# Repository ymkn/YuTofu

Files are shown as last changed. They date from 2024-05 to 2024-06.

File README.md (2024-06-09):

# YuTofu

YuTofu is an unofficial compatible PCB for the well-known custom keyboard [Tofu60 2.0](https://kbdfans.com/products/tofu60-2-0).

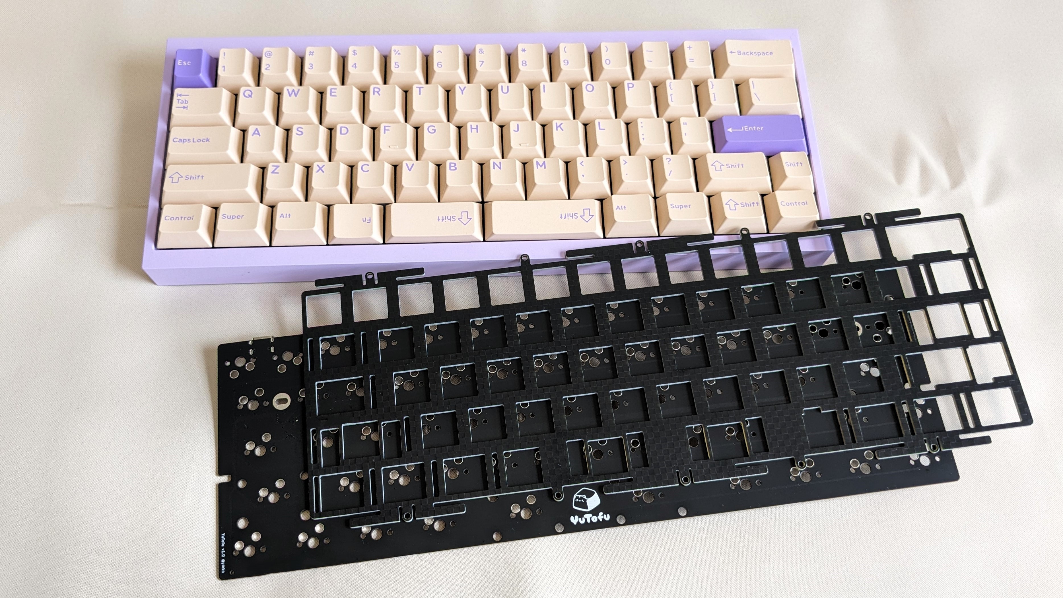
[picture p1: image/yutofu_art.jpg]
YuTofu Art


Based on an ANSI layout with splitted right-Shift and 6.25u spacebar, the spacebar area has been divided into 1.25u, 2.25u, and 2.75u sections. This allows for more effective use of the thumbs.

YuTofu is equipped with a 4-pin JSF socket compatible with [Unified Daughterboard](https://github.com/Unified-Daughterboard), in addition to an onboard USB Type-C connector and mounting holes compatible with the GH60-compatible layout. This means that the PCB can be used not only in the Tofu60 2.0 case but also in common GH60-compatible cases, i.e. [Tofu60 Redux Case](https://kbdfans.com/products/tofu60-redux-case).

## Default Layout

You can customize the layout with [Vial](https://get.vial.today/) configurator.

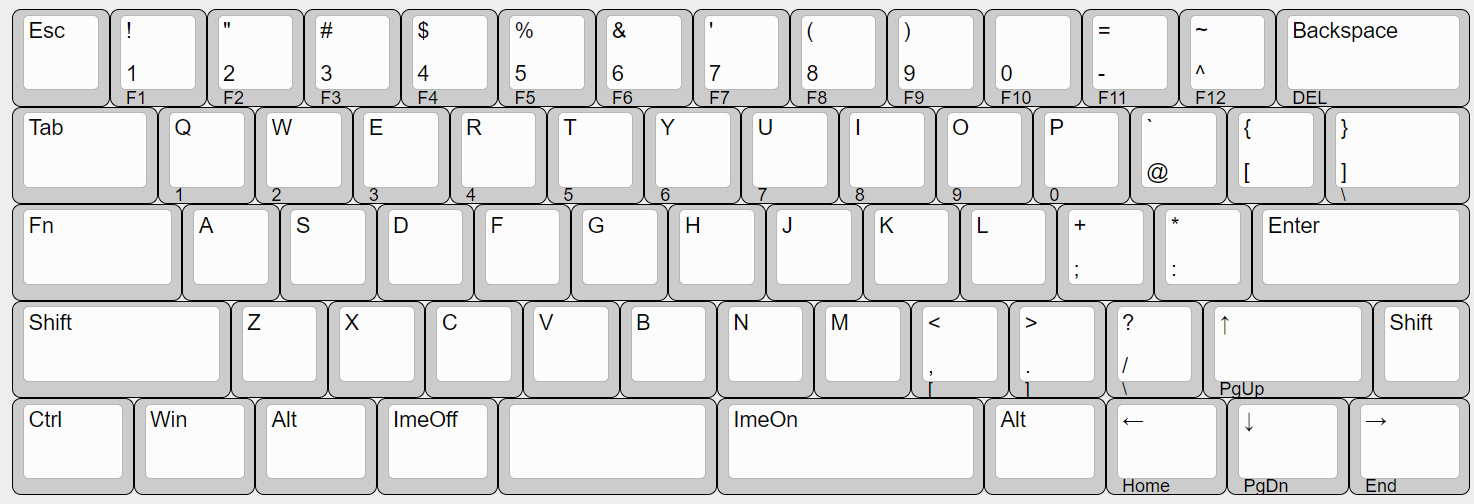
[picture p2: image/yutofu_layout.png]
Yutofu Layout


## Specification

- Hot swappable sockets for MX compatible switches are installed
- Unified-Daughterboard JSF 4-pin socket and USB Type C Connector (USB 2.0) are equipped
- PCB and switch plate compatible with the Tofu60 2.0
- GH60 compatible dimension: 285mm(w) x 94.6mm(h) x 1.6mm(d)
- Suitable for Tofu60 2.0 case, and also may be used for most 60% keyboard cases
  - Warning: center and right bottom mounting holes are not implemented.
  - Warning: switch plate cannot be used with cases other than the Tofu60 2.0.

## Build Guide

See [doc/buildguide.md](doc/buildguide.md)

## LICENSE

This project is licensed under the MIT License, see the [LICENSE file](LICENSE) for details.

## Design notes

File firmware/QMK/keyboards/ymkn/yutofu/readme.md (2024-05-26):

# ymkn/yutofu

YuTofu is an unofficial compatible PCB for the well-known custom keyboard [Tofu60 2.0](https://kbdfans.com/products/tofu60-2-0).

* Keyboard Maintainer: [ymkn](https://github.com/ymkn)

Make example for this keyboard (after setting up your build environment):

    make ymkn/yutofu:vial

Flashing example for this keyboard:

1. Enter the bootloader.
2. Simply copy ymkn_yutofu_vial.uf2 to RPI_RP2 drive.

This keyboard supports [Vial](https://get.vial.today/) configurator.

## Bootloader

Enter the bootloader in 2 ways:

* **Bootmagic reset**: Hold down the key at (0,0) in the matrix (usually the top left key or Escape) and plug in the keyboard
* **Physical reset button**: Briefly press the button on the back of the PCB - some may have pads you must short instead

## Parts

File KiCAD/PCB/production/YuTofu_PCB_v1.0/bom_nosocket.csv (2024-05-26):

Designator | Footprint | Quantity | Value | LCSC Part #
BTN1 | SW_Push_1P1T_XKB_TS-1187A | 1 | TS-1187A-B-A-B
C1, C2 | 0402 | 2 | 10uF
C10, C13, C16, C17, C3, C4, C5, C6, C7, C8, C9 | 0402 | 11 | 100nF
C11, C12 | 0402 | 2 | 1uF
C14, C15 | 0402 | 2 | 20pF
D1, D10, D11, D12, D13, D14, D15, D16, D17, D18, D19, D2, D20, D21, D22, D23, D24, D25, D26, D27, D28, D29, D3, D30, D31, D32, D33, D34, D35, D36, D37, D38, D39, D4, D40, D41, D42, D43, D44, D45, D46, D48, D49, D5, D50, D51, D52, D53, D54, D55, D56, D57, D58, D59, D6, D62, D63, D64, D65, D66, D67, D7, D8, D9 | D_SOD-123 | 64 | 1N4148W
J1 | USB_C_Receptacle_HRO_TYPE-C-31-M-12 | 1 | TYPE-C-31-M-12
J2 | JST_SH_SM04B-SRSS-TB_1x04-1MP_P1.00mm_Horizontal | 1 | Conn_01x04_MountingPin
R1, R3 | 0402 | 2 | 5.1K
R4, R5 | 0603 | 2 | 27
R6 | 0402 | 1 | 1KΩ
R7 | 0402 | 1 | 10kΩ
R8 | 0402 | 1 | 1K
U1 | SOT-23-3 | 1 | XC6206P332MR
U2 | SOT-363-6_2P2X1P35_ONS | 1 | SMF05CT1G
U3 | QFN-56-1EP_7x7mm_P0.4mm_EP3.2x3.2mm | 1 | RP2040
U4 | W25Q16JVUXIQ_WIN | 1 | W25Q16JVUXIQ
Y1 | Crystal_SMD_3225-4Pin_3.2x2.5mm | 1 | X322512MSB4SI

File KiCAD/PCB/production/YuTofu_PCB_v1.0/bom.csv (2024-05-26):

Designator | Footprint | Quantity | Value | LCSC Part #
BTN1 | SW_Push_1P1T_XKB_TS-1187A | 1 | TS-1187A-B-A-B
C1, C2 | 0402 | 2 | 10uF
C10, C13, C16, C17, C3, C4, C5, C6, C7, C8, C9 | 0402 | 11 | 100nF
C11, C12 | 0402 | 2 | 1uF
C14, C15 | 0402 | 2 | 20pF
D1, D10, D11, D12, D13, D14, D15, D16, D17, D18, D19, D2, D20, D21, D22, D23, D24, D25, D26, D27, D28, D29, D3, D30, D31, D32, D33, D34, D35, D36, D37, D38, D39, D4, D40, D41, D42, D43, D44, D45, D46, D48, D49, D5, D50, D51, D52, D53, D54, D55, D56, D57, D58, D59, D6, D62, D63, D64, D65, D66, D67, D7, D8, D9 | D_SOD-123 | 64 | 1N4148W
J1 | USB_C_Receptacle_HRO_TYPE-C-31-M-12 | 1 | TYPE-C-31-M-12
J2 | JST_SH_SM04B-SRSS-TB_1x04-1MP_P1.00mm_Horizontal | 1 | Conn_01x04_MountingPin
R1, R3 | 0402 | 2 | 5.1K
R4, R5 | 0603 | 2 | 27
R6 | 0402 | 1 | 1KΩ
R7 | 0402 | 1 | 10kΩ
R8 | 0402 | 1 | 1K
SW1, SW11, SW12, SW13, SW14, SW16, SW17, SW18, SW19, SW21, SW22, SW23, SW24, SW25, SW26, SW27, SW28, SW30, SW31, SW32, SW33, SW34, SW35, SW36, SW37, SW38, SW39, SW4, SW40, SW41, SW42, SW43, SW44, SW45, SW46, SW48, SW49, SW50, SW51, SW53, SW54, SW55, SW58, SW59, SW6, SW66, SW7, SW8, SW9 | SW_MX_HS_CPG151101S11_1u | 49 | SW_Push
SW10, SW15, SW20, SW5, SW52, SW57, SW62, SW67 | SW_MX_HS_CPG151101S11_1.25u | 8 | SW_Push
SW2 | SW_MX_HS_CPG151101S11_1.5u | 1 | SW_Push
SW29 | SW_MX_HS_CPG151101S11_1u | 1 | Space
SW3, SW56 | SW_MX_HS_CPG151101S11_1.75u | 2 | SW_Push
SW63 | SW_MX_HS_CPG151101S11_1u | 1 | Backspace
SW64 | SW_MX_HS_CPG151101S11_1.5u | 1 | Backslash
SW65 | SW_MX_HS_CPG151101S11_1u | 1 | Enter
U1 | SOT-23-3 | 1 | XC6206P332MR
U2 | SOT-363-6_2P2X1P35_ONS | 1 | SMF05CT1G
U3 | QFN-56-1EP_7x7mm_P0.4mm_EP3.2x3.2mm | 1 | RP2040
U4 | W25Q16JVUXIQ_WIN | 1 | W25Q16JVUXIQ
Y1 | Crystal_SMD_3225-4Pin_3.2x2.5mm | 1 | X322512MSB4SI

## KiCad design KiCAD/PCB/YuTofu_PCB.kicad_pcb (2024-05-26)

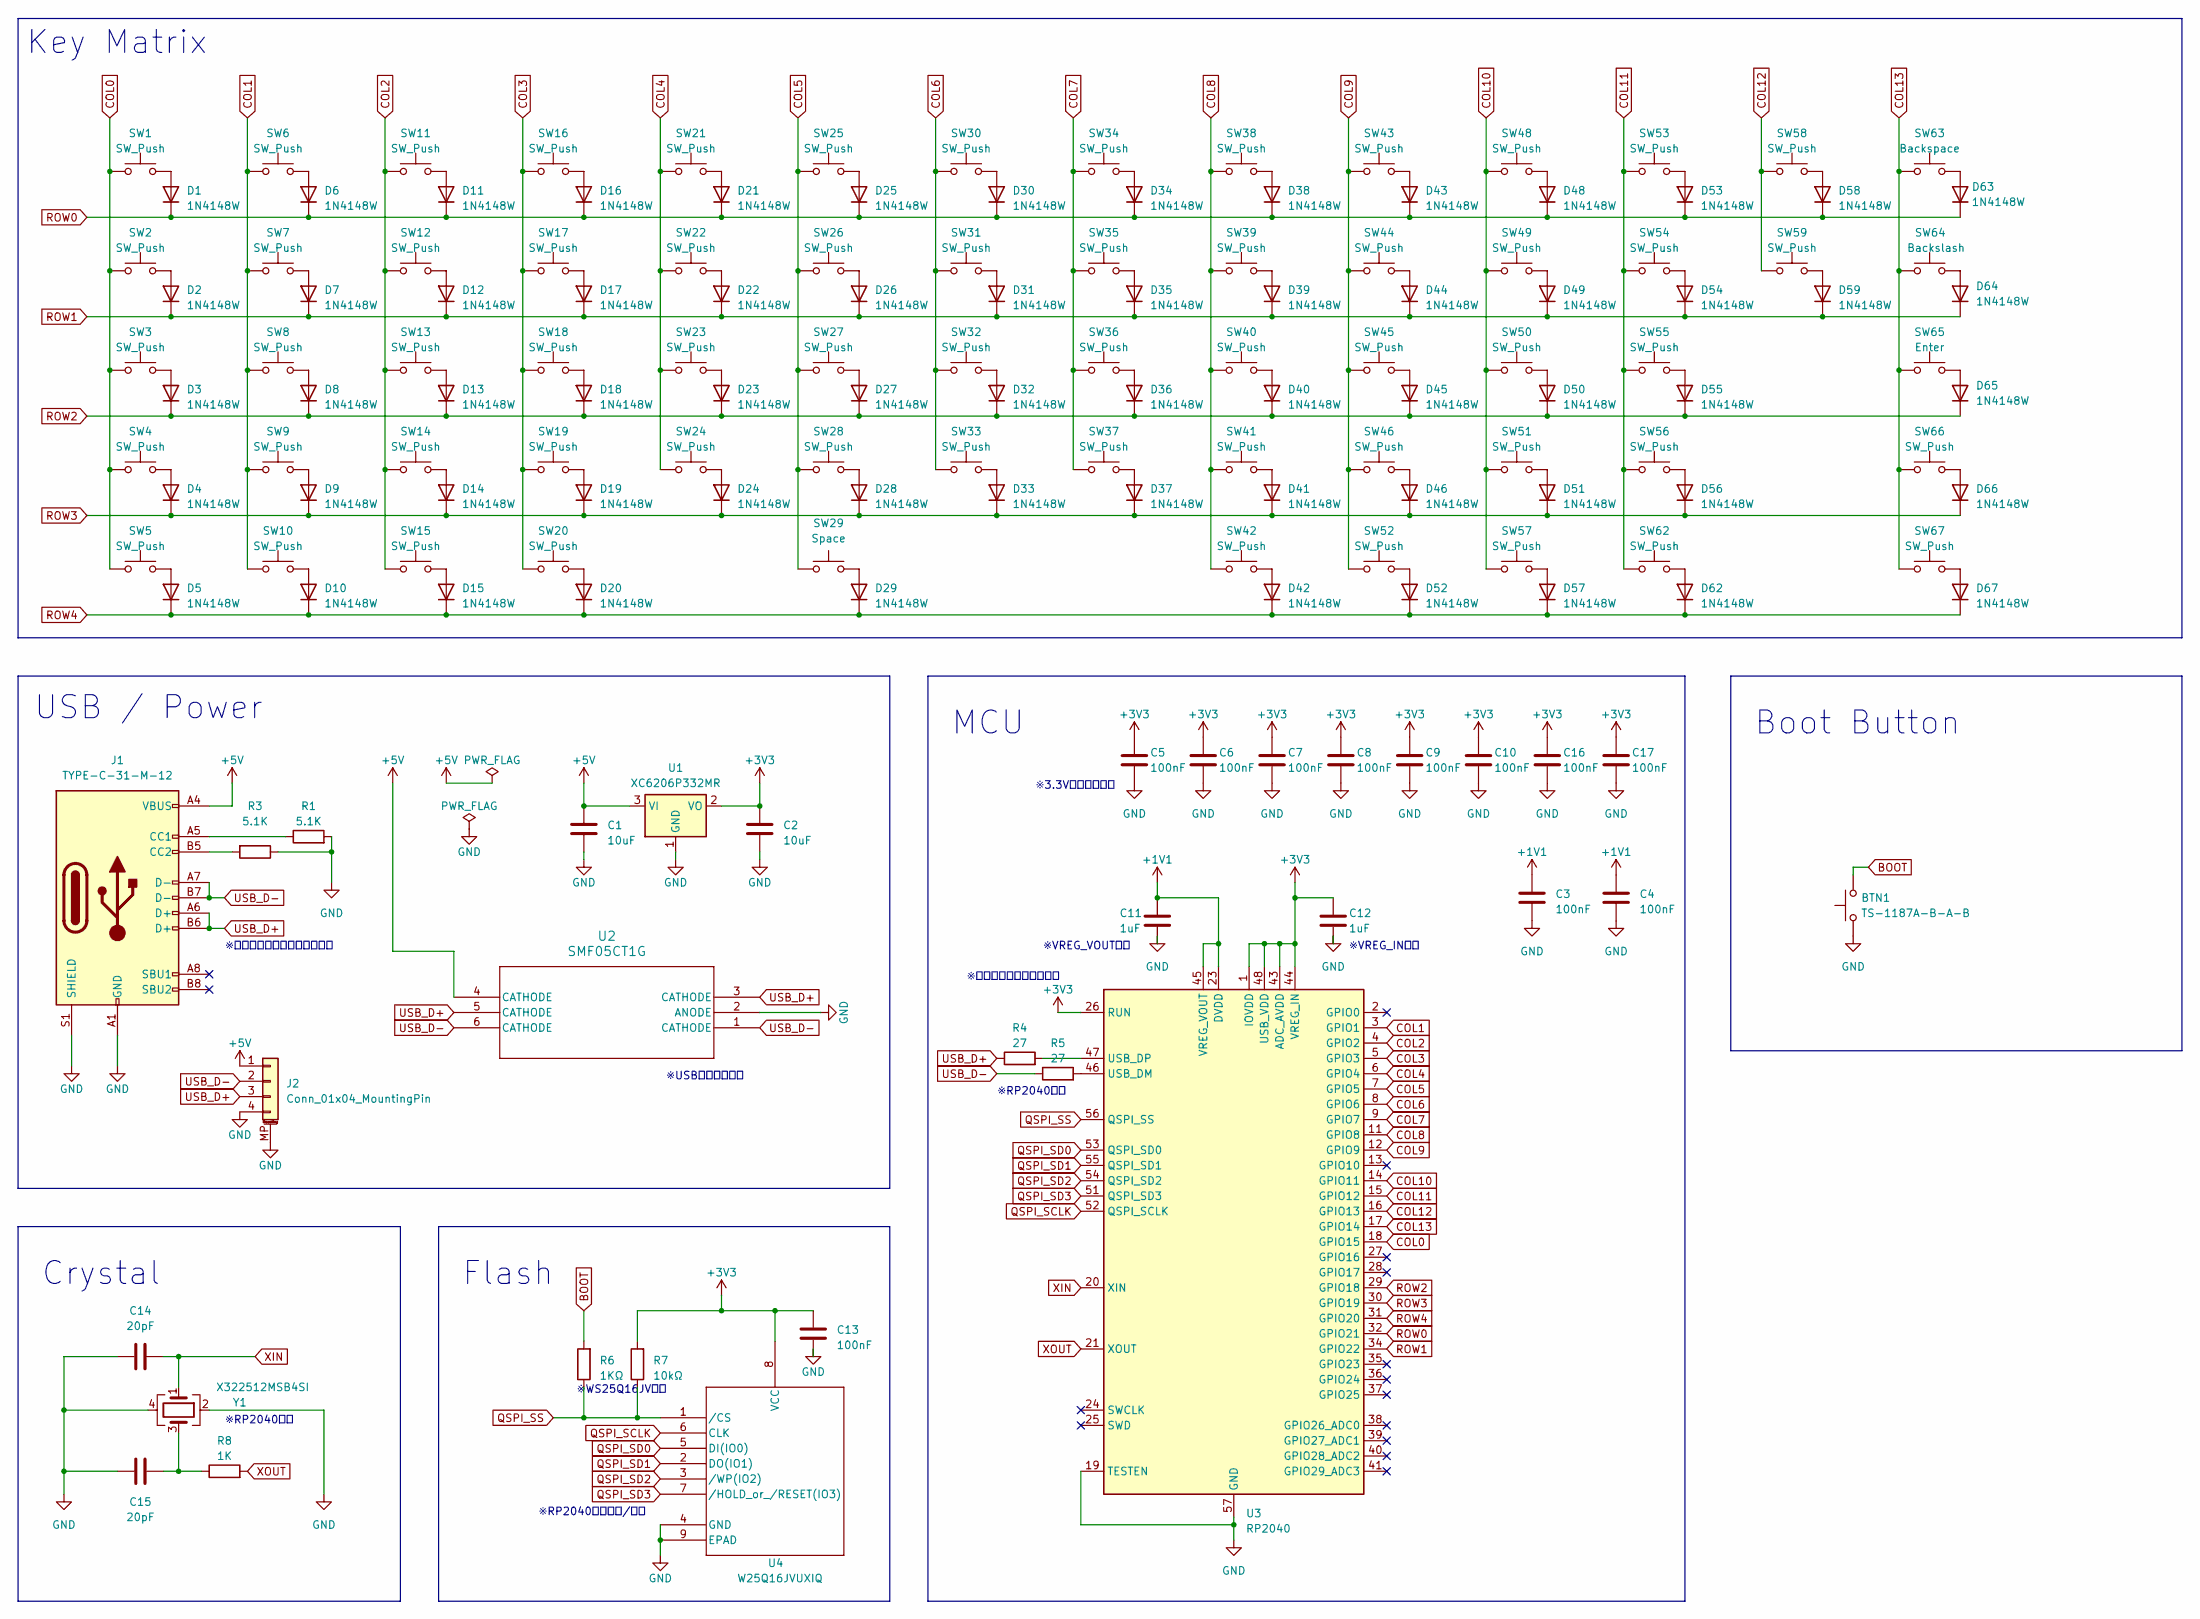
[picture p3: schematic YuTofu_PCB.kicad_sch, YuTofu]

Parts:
BTN1: TS-1187A-B-A-B; SW_Push_1P1T_XKB_TS-1187A; LCSC Parts # C318884
C1, C2: 10uF; C_0402_1005Metric; LCSC Parts # C15525
C3, C4, C5, C6, C7, C8, C9, C10, C13, C16, C17: 100nF; C_0402_1005Metric; LCSC Parts # C1525
C11, C12: 1uF; C_0402_1005Metric; LCSC Parts # C52923
C14, C15: 20pF; C_0402_1005Metric; LCSC Parts # C1554
D1, D2, D3, D4, D5, D6, D7, D8, D9, D10, D11, D12, D13, D14, D15, D16, D17, D18, D19, D20, D21, D22, D23, D24, D25, D26, D27, D28, D29, D30, D31, D32, D33, D34, D35, D36, D37, D38, D39, D40, D41, D42, D43, D44, D45, D46, D48, D49, D50, D51, D52, D53, D54, D55, D56, D57, D58, D59, D62, D63, D64, D65, D66, D67: 1N4148W; D_SOD-123; LCSC Parts # C7420318
J1: TYPE-C-31-M-12; USB_C_Receptacle_HRO_TYPE-C-31-M-12; LCSC Parts # C165948
J2: Conn_01x04_MountingPin; JST_SH_SM04B-SRSS-TB_1x04-1MP_P1.00mm_Horizontal; LCSC Parts # C160404
R1, R3: 5.1K; R_0402_1005Metric; LCSC Parts # C25905
R4, R5: 27; R_0603_1608Metric; LCSC Parts # C13167
R6: 1KΩ; R_0402_1005Metric; LCSC Parts # C11702
R7: 10kΩ; R_0402_1005Metric; LCSC Parts # C25744
R8: 1K; R_0402_1005Metric; LCSC Parts # C11702
SW1, SW4, SW6, SW7, SW8, SW9, SW11, SW12, SW13, SW14, SW16, SW17, SW18, SW19, SW21, SW22, SW23, SW24, SW25, SW26, SW27, SW28, SW30, SW31, SW32, SW33, SW34, SW35, SW36, SW37, SW38, SW39, SW40, SW41, SW42, SW43, SW44, SW45, SW46, SW48, SW49, SW50, SW51, SW53, SW54, SW55, SW58, SW59, SW66: SW_Push; SW_MX_HS_CPG151101S11_1u
SW2: SW_Push; SW_MX_HS_CPG151101S11_1.5u
SW3, SW56: SW_Push; SW_MX_HS_CPG151101S11_1.75u
SW5, SW10, SW15, SW20, SW52, SW57, SW62, SW67: SW_Push; SW_MX_HS_CPG151101S11_1.25u
SW29: Space; SW_MX_HS_CPG151101S11_1u
SW63: Backspace; SW_MX_HS_CPG151101S11_1u
SW64: Backslash; SW_MX_HS_CPG151101S11_1.5u
SW65: Enter; SW_MX_HS_CPG151101S11_1u
U1: XC6206P332MR; SOT-23-3; LCSC Parts # C5446
U2: SMF05CT1G; SOT-363-6_2P2X1P35_ONS; LCSC Parts # C15879
U3: RP2040; QFN-56-1EP_7x7mm_P0.4mm_EP3.2x3.2mm; LCSC Parts # C2040
U4: W25Q16JVUXIQ; W25Q16JVUXIQ_WIN; LCSC Parts # C2843335
Y1: X322512MSB4SI; Crystal_SMD_3225-4Pin_3.2x2.5mm; LCSC Parts # C9002

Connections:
+1V1: C3.1, C4.1, C11.1, U3.23 (DVDD), U3.45 (VREG_VOUT), U3.50 (DVDD)
+3V3: C2.1, C5.1, C6.1, C7.1, C8.1, C9.1, C10.1, C12.1, C13.1, C16.1, C17.1, R7.2, U1.2 (VO), U3.1 (IOVDD), U3.10 (IOVDD), U3.22 (IOVDD), U3.26 (RUN), U3.33 (IOVDD), U3.42 (IOVDD), U3.43 (ADC_AVDD), U3.44 (VREG_IN), U3.48 (USB_VDD), U3.49 (IOVDD), U4.8 (VCC)
+5V: C1.1, J1.A4 (VBUS), J1.A9 (VBUS), J1.B4 (VBUS), J1.B9 (VBUS), J2.1, U1.3 (VI), U2.4 (CATHODE)
BOOT: BTN1.2, R6.2
COL0: SW1.1, SW2.1, SW3.1, SW4.1, SW5.1, U3.18 (GPIO15)
COL1: SW6.1, SW7.1, SW8.1, SW9.1, SW10.1, U3.3 (GPIO1)
COL2: SW11.1, SW12.1, SW13.1, SW14.1, SW15.1, U3.4 (GPIO2)
COL3: SW16.1, SW17.1, SW18.1, SW19.1, SW20.1, U3.5 (GPIO3)
COL4: SW21.1, SW22.1, SW23.1, SW24.1, U3.6 (GPIO4)
COL5: SW25.1, SW26.1, SW27.1, SW28.1, SW29.1, U3.7 (GPIO5)
COL6: SW30.1, SW31.1, SW32.1, SW33.1, U3.8 (GPIO6)
COL7: SW34.1, SW35.1, SW36.1, SW37.1, U3.9 (GPIO7)
COL8: SW38.1, SW39.1, SW40.1, SW41.1, SW42.1, U3.11 (GPIO8)
COL9: SW43.1, SW44.1, SW45.1, SW46.1, SW52.1, U3.12 (GPIO9)
COL10: SW48.1, SW49.1, SW50.1, SW51.1, SW57.1, U3.14 (GPIO11)
COL11: SW53.1, SW54.1, SW55.1, SW56.1, SW62.1, U3.15 (GPIO12)
COL12: SW58.1, SW59.1, U3.16 (GPIO13)
COL13: SW63.1, SW64.1, SW65.1, SW66.1, SW67.1, U3.17 (GPIO14)
GND: BTN1.1, C1.2, C2.2, C3.2, C4.2, C5.2, C6.2, C7.2, C8.2, C9.2, C10.2, C11.2, C12.2, C13.2, C14.1, C15.1, C16.2, C17.2, J1.A1 (GND), J1.A12 (GND), J1.B1 (GND), J1.B12 (GND), J1.S1 (SHIELD), J2.4, J2.MP (MountPin), R1.2, R3.1, U1.1 (GND), U2.2 (ANODE), U3.19 (TESTEN), U3.57 (GND), U4.4 (GND), U4.9 (EPAD), Y1.2, Y1.4
unnamed: C15.2, R8.1, Y1.3
unnamed: D1.2 (A), SW1.2
unnamed: D2.2 (A), SW2.2
unnamed: D3.2 (A), SW3.2
unnamed: D4.2 (A), SW4.2
unnamed: D5.2 (A), SW5.2
unnamed: D6.2 (A), SW6.2
unnamed: D7.2 (A), SW7.2
unnamed: D8.2 (A), SW8.2
unnamed: D9.2 (A), SW9.2
unnamed: D10.2 (A), SW10.2
unnamed: D11.2 (A), SW11.2
unnamed: D12.2 (A), SW12.2
unnamed: D13.2 (A), SW13.2
unnamed: D14.2 (A), SW14.2
unnamed: D15.2 (A), SW15.2
unnamed: D16.2 (A), SW16.2
unnamed: D17.2 (A), SW17.2
unnamed: D18.2 (A), SW18.2
unnamed: D19.2 (A), SW19.2
unnamed: D20.2 (A), SW20.2
unnamed: D21.2 (A), SW21.2
unnamed: D22.2 (A), SW22.2
unnamed: D23.2 (A), SW23.2
unnamed: D24.2 (A), SW24.2
unnamed: D25.2 (A), SW25.2
unnamed: D26.2 (A), SW26.2
unnamed: D27.2 (A), SW27.2
unnamed: D28.2 (A), SW28.2
unnamed: D29.2 (A), SW29.2
unnamed: D30.2 (A), SW30.2
unnamed: D31.2 (A), SW31.2
unnamed: D32.2 (A), SW32.2
unnamed: D33.2 (A), SW33.2
unnamed: D34.2 (A), SW34.2
unnamed: D35.2 (A), SW35.2
unnamed: D36.2 (A), SW36.2
unnamed: D37.2 (A), SW37.2
unnamed: D38.2 (A), SW38.2
unnamed: D39.2 (A), SW39.2
unnamed: D40.2 (A), SW40.2
unnamed: D41.2 (A), SW41.2
unnamed: D42.2 (A), SW42.2
unnamed: D43.2 (A), SW43.2
unnamed: D44.2 (A), SW44.2
unnamed: D45.2 (A), SW45.2
unnamed: D46.2 (A), SW46.2
unnamed: D48.2 (A), SW48.2
unnamed: D49.2 (A), SW49.2
unnamed: D50.2 (A), SW50.2
unnamed: D51.2 (A), SW51.2
unnamed: D52.2 (A), SW52.2
unnamed: D53.2 (A), SW53.2
unnamed: D54.2 (A), SW54.2
unnamed: D55.2 (A), SW55.2
unnamed: D56.2 (A), SW56.2
unnamed: D57.2 (A), SW57.2
unnamed: D58.2 (A), SW58.2
unnamed: D59.2 (A), SW59.2
unnamed: D62.2 (A), SW62.2
unnamed: D63.2 (A), SW63.2
unnamed: D64.2 (A), SW64.2
unnamed: D65.2 (A), SW65.2
unnamed: D66.2 (A), SW66.2
unnamed: D67.2 (A), SW67.2
unnamed: J1.A5 (CC1), R1.1
unnamed: J1.B5 (CC2), R3.2
unnamed: R5.2, U3.46 (USB_DM)
unnamed: R4.2, U3.47 (USB_DP)
QSPI_SCLK: U3.52 (QSPI_SCLK), U4.6 (CLK)
QSPI_SD0: U3.53 (QSPI_SD0), U4.5 (DI(IO0))
QSPI_SD1: U3.55 (QSPI_SD1), U4.2 (DO(IO1))
QSPI_SD2: U3.54 (QSPI_SD2), U4.3 (/WP(IO2))
QSPI_SD3: U3.51 (QSPI_SD3), U4.7 (/HOLD_or_/RESET(IO3))
QSPI_SS: R6.1, R7.1, U3.56 (QSPI_SS), U4.1 (/CS)
ROW0: D1.1 (K), D6.1 (K), D11.1 (K), D16.1 (K), D21.1 (K), D25.1 (K), D30.1 (K), D34.1 (K), D38.1 (K), D43.1 (K), D48.1 (K), D53.1 (K), D58.1 (K), D63.1 (K), U3.32 (GPIO21)
ROW1: D2.1 (K), D7.1 (K), D12.1 (K), D17.1 (K), D22.1 (K), D26.1 (K), D31.1 (K), D35.1 (K), D39.1 (K), D44.1 (K), D49.1 (K), D54.1 (K), D59.1 (K), D64.1 (K), U3.34 (GPIO22)
ROW2: D3.1 (K), D8.1 (K), D13.1 (K), D18.1 (K), D23.1 (K), D27.1 (K), D32.1 (K), D36.1 (K), D40.1 (K), D45.1 (K), D50.1 (K), D55.1 (K), D65.1 (K), U3.29 (GPIO18)
ROW3: D4.1 (K), D9.1 (K), D14.1 (K), D19.1 (K), D24.1 (K), D28.1 (K), D33.1 (K), D37.1 (K), D41.1 (K), D46.1 (K), D51.1 (K), D56.1 (K), D66.1 (K), U3.30 (GPIO19)
ROW4: D5.1 (K), D10.1 (K), D15.1 (K), D20.1 (K), D29.1 (K), D42.1 (K), D52.1 (K), D57.1 (K), D62.1 (K), D67.1 (K), U3.31 (GPIO20)
USB_D+: J1.A6 (D+), J1.B6 (D+), J2.3, R4.1, U2.3 (CATHODE), U2.5 (CATHODE)
USB_D-: J1.A7 (D-), J1.B7 (D-), J2.2, R5.1, U2.1 (CATHODE), U2.6 (CATHODE)
XIN: C14.2, U3.20 (XIN), Y1.1
XOUT: R8.2, U3.21 (XOUT)

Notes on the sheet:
※RP2040近傍
Flash
Key Matrix
※リセットボタン実装無し
USB / Power
※WS25Q16JV近傍
※USBコネクタ近傍
※差動信号、配線長さ合わせる
※VREG_IN近傍
Boot Button
MCU
※3.3V電源ピン近傍
※RP2040近傍配置/直結
※VREG_VOUT近傍
Crystal

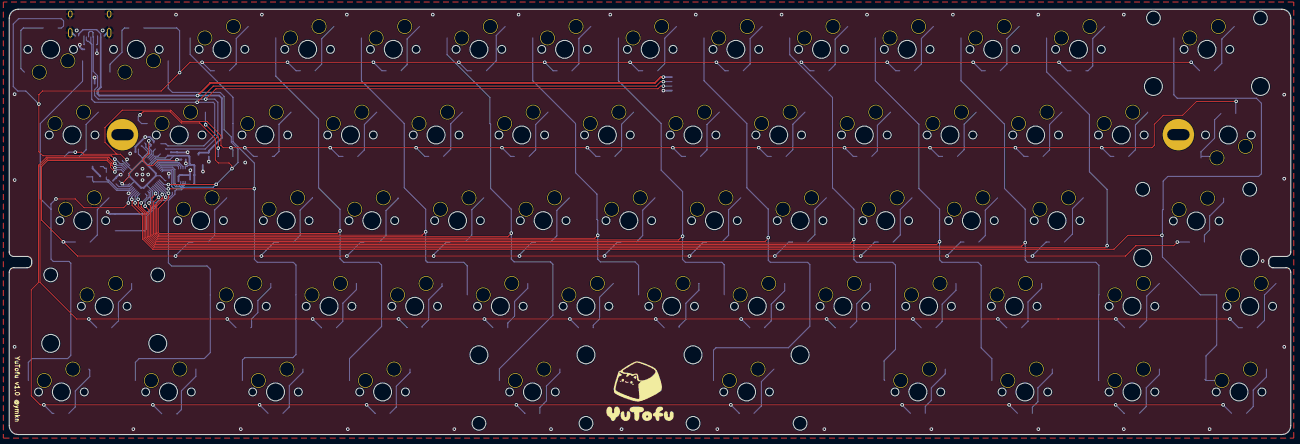
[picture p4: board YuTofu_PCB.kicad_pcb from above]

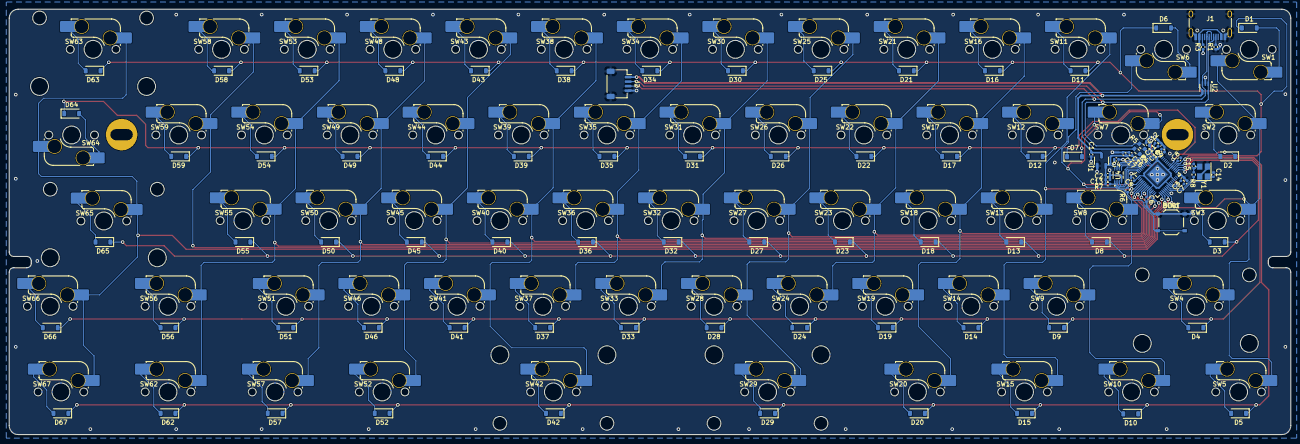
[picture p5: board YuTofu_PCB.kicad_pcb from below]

Board: 2 copper layers, 285.1 x 94.6 mm, 160 parts (160 on the bottom side), 103 nets.

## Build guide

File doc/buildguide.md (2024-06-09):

# YuTofu ビルドガイド

## 1. はじめに

本書は[Tofu60 2.0](https://kbdfans.com/products/tofu60-2-0)互換の自作キーボード基板であるYuTofuのビルドガイドです。Tofu60 2.0との組み合わせ利用以外は想定しておりませんのでご留意ください。

申し訳ないのですがYuTofu固有でない一般のご質問や、互換性確認済みケース以外についてのご質問にはお答えできません。各自お調べください。

> [!CAUTION]
> <em style="color: red; font-style: normal; font-weight: bold;">JSTコネクタとYuTofu基板上のUSBコネクタを同時にPCへ接続しないでください。YuTofuやPCの故障の危険性があります。</em>JSTコネクタ利用時はドーターボード側のUSBコネクタのみを使用し、YuTofu基板上のUSBコネクタを使用する場合はJSTコネクタに何も接続しないでください。

## 2. 準備

### 2.1 内容物確認

|品目|数量|
|---|---|
|YuTofu 基板|1|
|YuTofu スイッチプレート (Tofu60 2.0互換)|1|

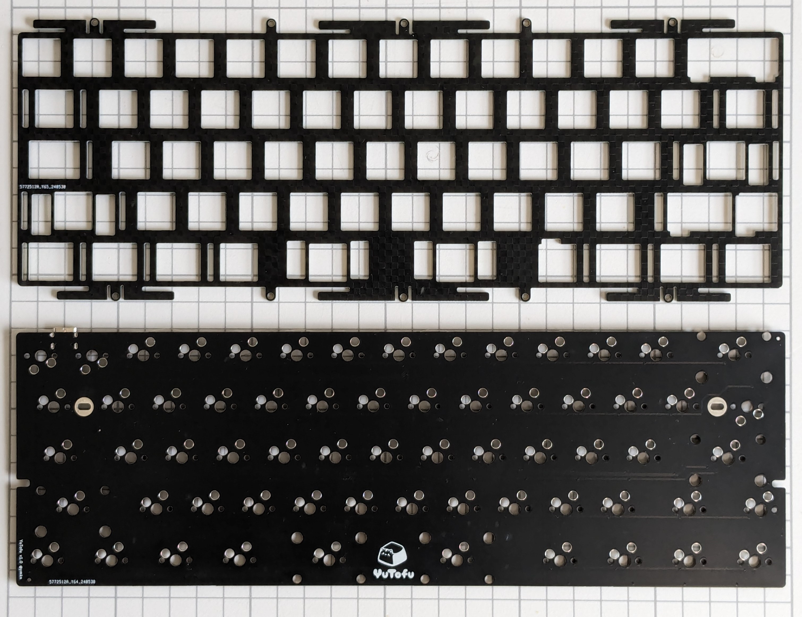
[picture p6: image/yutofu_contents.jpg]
YuTofu内容物


### 2.2 別途用意が必要な部品

下記部品は国内外の自作キーボード専門店や電子部品販売店などから別途調達してください。

|品目|数量|備考|
|---|---|---|
|MX互換キースイッチ|64|[Cherry MX](https://www.cherrymx.de/en/dev.html)もしくはその互換品|
|MX互換スイッチソケット|64|[Kailh PCB Socket CPG151101S11](https://www.kailhswitch.com/mechanical-keyboard-switches/box-switches/mechanical-keyboard-switches-kailh-pcb-socket.html)もしくはその互換品|
|MX互換キーキャップ|-|[Cherry MX](https://www.cherrymx.de/en/dev.html)もしくはその互換品|
|2uサイズPCBマウント型スタビライザー|5|幅の広いキーの押し下げを安定させる部品です。Backspaceキー、左Shiftキー、Enterキー、2.25uスペース、2.75uスペースに用います|
|スタビライザー用シム (0.4mm厚)|2x5|スタビライザーの下に敷いて高さを調節するための部品です。YuTofu基板の厚みは1.2mmとなっているため、一般的な1.6mm基板用のスタビライザー1つごとに2つ必要になります。ただしスイッチフォームなど別の方法で高さを調整済みの場合は不要となります|
|Tofu60 2.0ケース|1|[Tofu60 2.0 Case](https://kbdfans.com/collections/case/products/tofu60-2-0-case)から、お好みのデザインのものを選択ください。似た名前の商品（Tofu65 2.0やTofu60 Redux等）がありますが、それらとは互換性がありませんので間違えないように注意してください。<br>PCBの外形寸法およびUSBコネクタ位置はGH60互換となっているため、その他のGH60互換ケースで使える可能性はありますが自己責任にてお願いいたします。|
|ドーターボード|1|Tofu60 2.0ケースには含まれないようです。[Tofu60 2.0 Accessories](https://kbdfans.com/collections/tofu60-2-0/products/tofu60-2-0-accessories)にあるDaughterboardが適合しますので入手してください。<br>このドーターボードは[Unified Daughterboard C series](https://unified-daughterboard.github.io/#/db-spec-c)互換と思われますので、同互換品が利用可能な可能性がありますが自己責任にてお願いします。|

#### 必要なキーキャップとサイズ

分割スペースキーを採用していますので、一般的なANSIキーキャップセットに加え、2.75uと2.25uサイズのスペースキーがそれぞれ1つずつ必要です。

右Shiftを分割するレイアウトを採用していますので、右Shiftキーは1.75uのものが必要です。

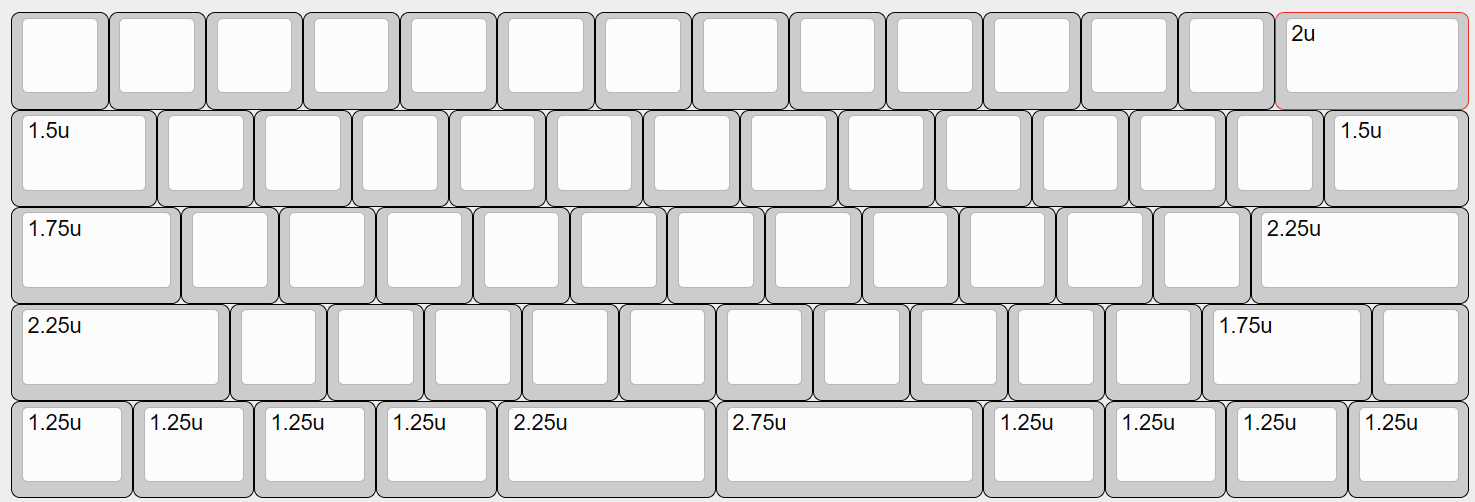
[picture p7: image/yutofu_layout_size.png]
レイアウト


## 3. 組み立て

### 3.1 スイッチソケットのはんだ付け

スイッチソケットは基板の裏面（ICチップ等が実装されている面）に取り付けます。L字状のガイドが白線でキー数分印刷されていますので、そのすべてにスイッチソケットをはんだ付けします。

ICチップ近辺のソケット（<span style="color: red">■</span>赤枠部分）をはんだ付けする際は、はんだごてで電子部品をを焼いてしまわないように気を付けてください。JSTコネクタ（<span style="color: violet">■</span>紫枠部分）も同様に注意ください。

すべてのスイッチソケットが基板に密着しており、ソケット両端とも漏れなくはんだ付けされているか確認してください。基板から浮いていたり、はんだ付けができていないとキースイッチの動作不良の原因になります。

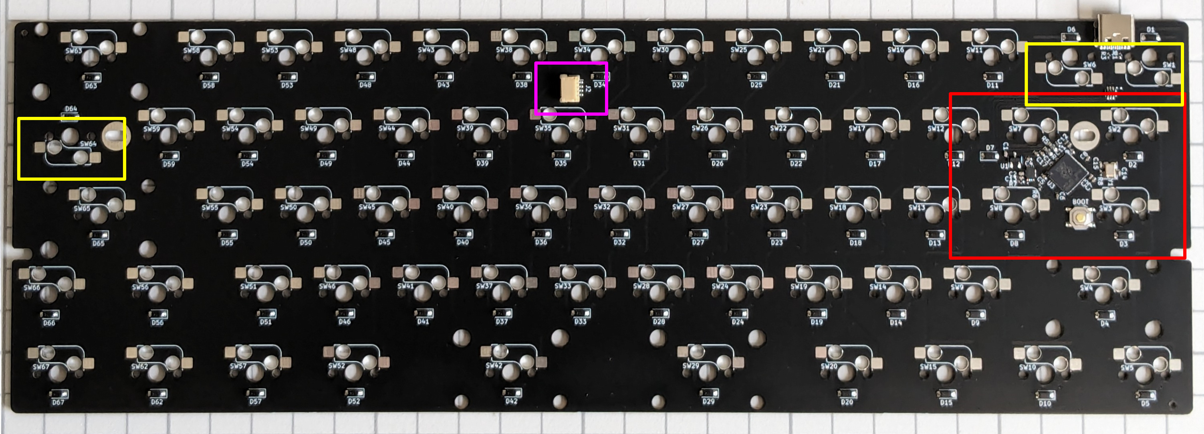
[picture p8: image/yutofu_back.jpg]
YuTofu裏面


> [!CAUTION]
> 最上段の右端2つ、2段目左端の3つだけ、スイッチソケットの向きが上下逆になっているので注意してください（<span style="color: yellow">■</span>黄色枠部分）。

### 3.2 スタビライザーの取り付け

スタビライザーは基板の表面（ロゴが印刷されている面）に取り付けます。

Backspaceキー、左Shiftキー、Enterキー、スペースキー（2.25、2.75）に2uサイズのスタビライザーを取り付けます。取り付け方はスタビライザーごとに異なりますが、一般には大きい穴の方にツメを引っかけ、小さい穴の方にプッシュピンを差し込む、もしくはネジ留めを行います。

シムを用いる場合は基板とスタビライザーの間に挟むように設置してください。

### 3.3 スイッチの取り付け

キースイッチはトッププレートを通して基板のソケットに差し込みます。すべてのキースイッチを一度に取り付けてしまうと基板に差し込むのが大変なので、まずトッププレートの四隅にキースイッチを取り付けて基板に差し込み、その後残りのスイッチを取り付けていくのがおすすめです。

### 3.4 ケースへの取り付け

Tofu60 2.0ケースへの取り付けはTofu60 2.0公式の[チュートリアル](https://www.notion.so/Tofu60-2-0-Building-tutorial-En-9c9b5f84711a4535b2f4f092510302da)や[ビルドビデオ](https://www.youtube.com/watch?v=rxgFLHTjNlE)を参照してください。

> [!CAUTION]
> <em style="color: red; font-style: normal; font-weight: bold;">JSTコネクタとYuTofu基板上のUSBコネクタを同時にPCへ接続しないでください。YuTofuやPCの故障の危険性があります。</em>JSTコネクタ利用時はドーターボード側のUSBコネクタのみを使用し、YuTofu基板上のUSBコネクタを使用する場合はJSTコネクタに何も接続しないでください。

> [!NOTE]
> JSTコネクタのピンアサイン、端子の向きはTofu60 2.0と同じです。
> 
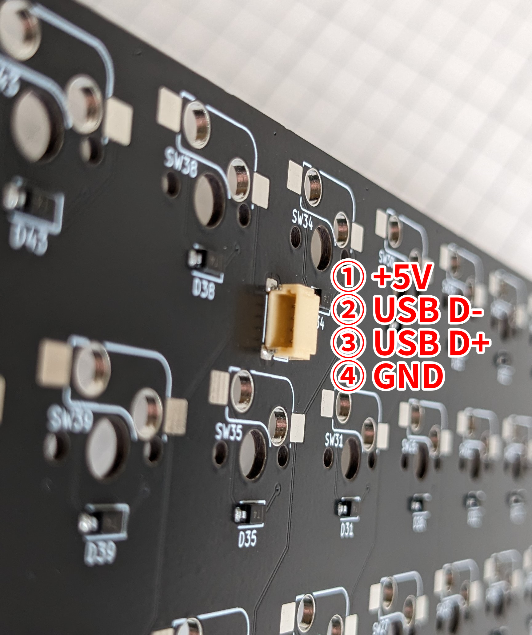
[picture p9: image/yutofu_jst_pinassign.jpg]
> 

基板をケースに取り付けられれば完成です！

## 4. 使用

## 4.1 コンピュータとの接続

お使いのコンピュータのUSB 2.0に対応したUSBコネクタと接続してください。即時利用できるはずです。

## 4.2 キーマップのカスタマイズ

本キーボードは[Vial](https://get.vial.today/)というキーマップ変更ツールに対応しています。Vialの詳しい使いかたはVialのドキュメントや世間の情報を参考にしてください。

## 5. その他

### 5.1 ブートモードの入り方

RP2040のブートモードに入るには、左上のキー（Escキー）を押しながらUSBケーブルを接続します。

もしくは、基板裏面のBOOTスイッチを押しながらUSBケーブルを接続します。

### 5.2 ファームウェアのありか

本リポジトリ内で公開しています。

https://github.com/ymkn/YuTofu/blob/main/firmware/QMK/ymkn_yutofu_vial.uf2

### 5.3 ソースコード/設計データのありか

本リポジトリ内で公開しています。MITライセンスです。

https://github.com/ymkn/YuTofu

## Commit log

2024-05-26 スイッチプレート付属になったので該当箇所を修正
2024-06-09 「ろ」キーの割り当て
2024-06-09 ドキュメントの最新化、画像の追加
